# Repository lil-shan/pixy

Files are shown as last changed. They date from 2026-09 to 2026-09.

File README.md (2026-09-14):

# UNO Q LED Matrix

Driving a Waveshare 64×32 HUB75 RGB LED matrix from an Arduino UNO Q, with a
XIAO ESP32-S3 acting as the panel's display adapter.

All rendering — fonts, images, GIFs, scrolling, effects — runs in Python on the
UNO Q's Linux side. The ESP32 holds no application logic at all: it receives
finished RGB565 frames and copies them to the panel.

## Why there's a second microcontroller

A HUB75 panel has no framebuffer and no PWM of its own. Something must
continuously bit-bang thirteen signals at ~100+ full refreshes per second, with
binary code modulation layered on top for colour depth. That needs either DMA
hardware or a dedicated real-time core.

Neither half of the UNO Q can do it well. Linux userspace has no real-time
guarantee, so GPIO bit-banging flickers; and the standard Linux HUB75 library
(`rpi-rgb-led-matrix`) pokes BCM2835 registers directly and is Raspberry
Pi-specific. The STM32U585 is fast enough in principle, but Adafruit_Protomatter
has no U5 support — its STM32 backend is gated on `STM32F4_SERIES`.

So the pixel pump is offloaded to an ESP32-S3, which drives HUB75 over GDMA with
almost no CPU cost. It's the same reasoning you'd use to pick a dedicated
display driver IC. The interesting work stays on the UNO Q.

## Architecture

```
  ┌─────────────────────────┐         ┌──────────────────┐      ┌─────────┐
  │ UNO Q (Debian, Python)  │  WiFi   │ XIAO ESP32-S3    │HUB75 │ 64×32   │
  │ Pillow: text, images,   │────────►│ receives RGB565, │─────►│ panel   │
  │ GIFs, scrolling         │  TCP    │ blits via GDMA   │      │         │
  └─────────────────────────┘  :3333  └──────────────────┘      └─────────┘
                                                                     ▲
                                                     5V 2.5A supply ─┘
```

Measured throughput: **114 fps** over WiFi, **103 fps** over USB serial. A frame
is 4096 bytes (64×32 × RGB565), so the link was never the constraint.

## Hardware

| Part | Notes |
|---|---|
| Arduino UNO Q | Debian image `BUILD_ID=20251111-426` |
| Seeed XIAO ESP32-S3 | **External antenna required** — no PCB antenna |
| Waveshare RGB-Matrix-P3-64x32 | 1/16 scan, HUB75E connector |
| 5 V / 2.5 A supply | Panel only, via the VH4 socket |

## Wiring

HUB75 needs 13 signals. The XIAO exposes 11 edge GPIO plus four rear JTAG pads,
so two rear pads carry the two least timing-critical lines.

| HUB75 pin | Signal | XIAO | GPIO |
|---|---|---|---|
| 1 | R1 | D0 | 1 |
| 2 | G1 | D1 | 2 |
| 3 | B1 | D2 | 3 |
| 4 | GND | GND | — |
| 5 | R2 | D3 | 4 |
| 6 | G2 | D4 | 5 |
| 7 | B2 | D5 | 6 |
| 8 | E | *unconnected* | — |
| 9 | A | D6 | 43 |
| 10 | B | rear pad MTDI | 41 |
| 11 | C | rear pad MTDO | 40 |
| 12 | D | D7 | 44 |
| 13 | CLK | D8 | 7 |
| 14 | LAT | D9 | 8 |
| 15 | OE | D10 | 9 |
| 16 | GND | GND | — |

Pin 8 is the E address line, unused on a 1/16 scan panel. Power the panel from
its own 5 V supply — never from the XIAO's 5V pin — and keep grounds common.

## Control deck

| Control | Pin | Notes |
|---|---|---|
| Dial — CLK / DT / SW | D2 / D3 / D4 | HW-040 module |
| Up / Down / Left / Right | D8 / D9 / D10 / D11 | Big tactile, internal pull-ups |
| A / B | D12 / A1 | Small tactile |
| Buzzer | A0 | Passive piezo — an active one ignores the frequency |

One dial only. A second encoder was tried and abandoned; `enc(1)` is still
wired through and returns 0, so one can be added later without touching any
game.

## Controls

The grammar never varies, on any screen:

| Control | Always does |
|---|---|
| Dial | Move through choices, set a value |
| A | Confirm, act |
| B | Back, cancel |
| D-pad | Direction, inside games |

Every screen carries a hint bar saying what A and B do right now, every game
opens with a two-line help card, and a first-run tutorial makes you use each
control once before it lets you into the menus.

**Common rails.** All grounds are shorted together across the panel supply, the
XIAO, the UNO Q and every button return. Both HW-040 modules share one 3.3 V rail
from the UNO Q header.

**Feed the HW-040s from 3V3, not 5V.** They carry onboard pull-ups to VCC, so a
5 V supply puts 5 V onto the UNO Q's 3.3 V-logic inputs. Their onboard pull-ups
also mean you don't need external ones on CLK/DT.

**D13 is unusable as a button input.** It drives the onboard LED, whose series
resistor to ground divides against the ~40 kΩ internal pull-up and holds the pin
below threshold — a button there reads as permanently pressed. That's why B is
on A1.

See [BUILDLOG.md](BUILDLOG.md) for the full iteration history — every failure,
its cause and its fix.

## Enclosures

Two printed parts, each a tray plus a lid:

| File | Size | Holds |
|---|---|---|
| `case/enclosure/display_housing.stl` | 199 × 104 × 45 mm | panel, XIAO, power bank |
| `case/enclosure/handheld_controller.stl` | 128 × 88 × 35 mm | UNO Q, control deck, battery |

`case/pixy_case.scad` is an alternative single-piece desktop cabinet —
parametric, designed but not yet printed.

See [HACKSTER.md](HACKSTER.md) for the full build guide.

## Setup

**ESP32 side**

```bash
cp xiao_wifi/secrets.h.example xiao_wifi/secrets.h   # then fill in your SSID/password
arduino-cli compile --fqbn esp32:esp32:XIAO_ESP32S3 \
  --board-options USBMode=hwcdc -u -p /dev/ttyACM0 xiao_wifi
```

The panel displays its own IP address on boot, so no serial monitor is needed to
find it.

**UNO Q side**

```bash
sudo apt install -y python3-pil
python3 -c "
from panel import Panel
p = Panel(host='192.168.1.64')
p.text('HELLO')
"
```

## Learning games

Six, each with its own adaptive level:

| Game | Teaches |
|---|---|
| Gate Keeper | AND / OR / XOR / NAND / NOR |
| Bit Flip | binary place value |
| Pattern | arithmetic, geometric and Fibonacci sequences |
| Ohm's Way | V = I x R, and rearranging it |
| Gear Lab | ratios |
| Angle | degrees, with the dial as a protractor |

**They adapt independently, across eight levels.** Two first-try corrects in a
row moves that game up; two wrong answers moves it down. The bar to climb
rises with the level -- two in a row early, three from level 4, four from
level 6 -- so the top is earned rather than stumbled into. Roughly twenty
clean answers to reach level 8.

What changes as you climb:

| Game | At the top |
|---|---|
| Gates | the gate stops telling you what it is; deduce it by experiment |
| Bit Flip | 8 bits, and the running total is hidden -- sum it yourself |
| Pattern | squares and growing-gap sequences, not just constant steps |
| Ohm's Way | awkward numbers, any of the three unknown |
| Gear Lab | real ratios like 5:3, not whole multiples |
| Angle | any angle, no readout, within 3 degrees by eye |

Two first-try corrects in a row moves that game up a level; two wrong moves it
down. A kid who has binary cold but
finds ratios hard gets hard binary and gentle ratios at the same time, which a
single global difficulty could never do. Charge paid scales with level, so
pushing yourself beats farming easy rounds.

**They explain.** A wrong answer opens a one-line card saying *why* -- "V = I
X R / 3 X 3 = 9", "5 IS / 4+1", "ADD 4 EACH / SO 19" -- then puts you back on
the same problem. Being told you are wrong teaches nothing on its own.

## API

```python
from panel import Panel

p = Panel(host='192.168.1.64')   # WiFi
p = Panel()                      # or USB serial, autodetected

p.text('HELLO')                            # centred, auto-shrinks to fit
p.scroll('longer message', speed=0.02)     # any length, any font
p.image('logo.png')                        # scaled, aspect preserved
p.gif('animation.gif')                     # honours per-frame timing
p.brightness(60)
p.clear()
p.ping()                                   # round-trip check
```

## Protocol

```
0xA5 0x5A <cmd> <len:uint16 LE> <payload...>
  0x01  frame       4096 bytes RGB565, big endian per pixel
  0x02  brightness  1 byte
  0x03  clear       no payload
  0x04  ping        no payload
```

Each handled command is acknowledged with a single `0x06` byte, so the host can
verify delivery rather than relying on someone watching the panel.

## Sketches

| Sketch | Purpose |
|---|---|
| `xiao_wifi` | **Main.** WiFi receiver, TCP server on :3333 |
| `xiao_receiver` | Same receiver over USB serial |
| `xiao_panel` | Standalone demo — colour bars, scrolling text, bitmap |
| `xiao_diag` | Slow static diagnostic: flat fills, half-split, row sweep |
| `xiao_addr` | Identifies which address line is wired where |

## Things that bit us

Kept because every one cost real debugging time.

- **The XIAO ESP32-S3 has no PCB antenna.** Without the u.FL antenna attached it
  saw 4 networks at −85 dBm and could not associate. With it: 16 networks,
  −39 dBm. A 45 dB difference that presents as "wrong WiFi password".
- **`Tinker Space` was 5 GHz only.** The ESP32-S3 is 2.4 GHz only, so it could
  never have joined regardless of credentials.
- **Address lines B and D were crossed.** Every row lit, but in scrambled order —
  a pure permutation. Fixed in software by swapping the pin defines; `xiao_addr`
  identifies the mapping in one static image.
- **USB CDC RX buffer defaults to 256 bytes.** Against a 4096-byte frame, every
  full frame arrived truncated while ping and brightness worked perfectly.
  `Serial.setRxBufferSize(8192)` before `begin()`.
- **Reading the two magic bytes in one pass desynchronises the stream** whenever
  `0xA5` lands at the end of a USB packet. Track the previous byte across loop
  iterations instead.
- **pyserial asserts DTR and RTS on open**, which on the S3's USB Serial/JTAG
  peripheral drives reset and boot-mode selection. Clear both *before* opening.
- **Driving an unpowered panel back-feeds it** through the input ESD clamp
  diodes, lighting it dimly with garbage and browning out the XIAO. Power the
  panel first, then the XIAO.

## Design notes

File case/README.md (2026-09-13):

# Pixy enclosure

A wedge cabinet. The LED panel leans back ~10°, the control deck slopes ~18°
toward the player. Three printed parts, none needing supports.

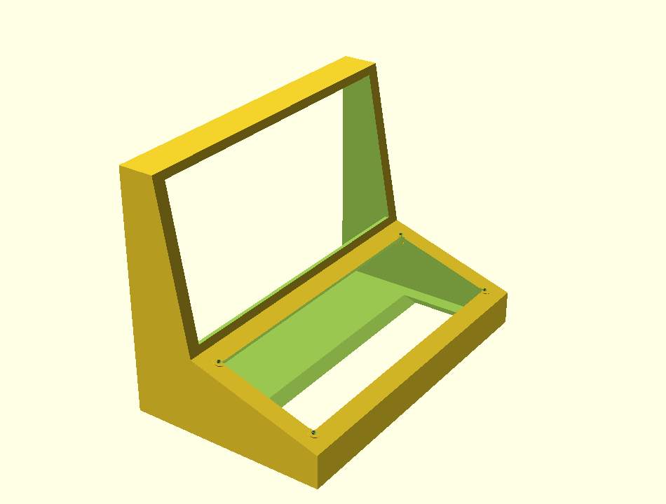
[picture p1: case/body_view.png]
body


## Parts

| Part | Size (mm) | Material | Orientation |
|---|---|---|---|
| `body` | 127 × 210 × 156 | ~194 g | On its **back face**, flat on the bed |
| `deck` | 83 × 203 × 3 | ~60 g | Flat |
| `back` | 203 × 153 × 3 | ~99 g | Flat |

Figures are 100% infill. At 20% with 3 perimeters expect roughly 40–50% of
that, so around **150 g** for the set.

**You need a 220 × 220 bed.** The widest part is 210 mm. Tell me if yours is
smaller and I'll add a split with alignment pins — `W` is parametric, but the
panel is 192 mm wide so the cabinet cannot shrink below about 206 mm.

## Print settings

- 0.2 mm layers, 3 perimeters, 20% infill
- No supports. Every overhang is either a wall or the ~18° deck, both fine
- Brim on `body` — it is tall with a modest footprint

## Assembly

1. **Panel** drops into the recess behind the screen aperture, from inside.
   The aperture is 4 mm smaller than the panel all round, so it seats against
   that lip and can't fall forward. Retain it with a dab of hot glue at each
   corner, or four small printed clips.
2. **Controls** push into the `deck` plate from behind: encoders through the
   7.6 mm holes with their own nuts, 12 mm tactiles into the big holes, 6 mm
   into the small pair, piezo behind the grille.
3. **Deck** sits on the ledge and screws down into the four bosses with M3 ×
   10. The plate sits proud by 3 mm — deliberate, so the ledge takes the load
   rather than the panel face.
4. **UNO Q and XIAO** mount inside on the base. There's room behind the deck.
5. **Back cover** screws on last. The vent slots sit over the UNO Q, and the
   cable exit at the bottom takes the panel's 5 V feed.

## Before you print

Three dimensions in the `.scad` are estimates I could not verify. Measure
yours and edit the top of the file — everything else derives from them.

```
panel_w = 192;   // confirmed from Waveshare's spec
panel_h = 96;    // confirmed
pcb_t   = 8;     // ESTIMATE  bare PCB depth
back_t  = 14;    // ESTIMATE  total depth including IDC connectors
```

`pcb_t` is the one that matters. Too small and the panel won't seat; too large
and it rattles. Measure the PCB alone, not including the connectors.

Also check `clear = 0.4`. That is the slip fit between printed parts — raise
it if your printer runs tight.

## Rendering

```bash
openscad -D 'part="body"' -o body.stl pixy_case.scad
openscad -D 'part="deck"' -o deck.stl pixy_case.scad
openscad -D 'part="back"' -o back.stl pixy_case.scad
```

Leave `part` unset to see all three laid out together.

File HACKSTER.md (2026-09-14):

# Pixy — a handheld STEM console that runs on what you learn

**Solve engineering puzzles on a 64×32 LED matrix, bank the Charge you earn,
and spend it in the arcade. Two wireless units, built on the Arduino UNO Q —
and it uses both of its brains.**

> 📷 `docs/img/screens/console-home.jpeg` — the console, powered up
> 🎬 **VIDEO — upload `pixyvideo5.mp4` to YouTube and embed here.** Pattern
> solved, then a **LEVEL 2** promotion banner. It shows the adaptive system
> working in five seconds, better than any paragraph.

---

## Why I built this

Most STEM toys pick a side. Either they teach, and feel like homework with
LEDs on it — or they entertain, and the learning is a thin coat of paint over
a game the kid would rather just play.

Pixy makes the learning **the power source**. Every puzzle you solve pays
*Charge*. Charge is what unlocks the arcade — Breakout, Pong, Snake, Simon. A
kid who wants to play Pong gets there by working out gear ratios. That is the
entire design, and everything else follows from it.

Two decisions came out of that, and both went against my first instinct:

**Arcade unlocks are permanent, not pay-per-play.** Charging per play turns
learning into a toll booth, and a kid who runs short simply stops. A one-time
unlock gives you something to work toward that then keeps giving.

**Difficulty adapts per game, not globally.** A kid who has binary cold but
finds ratios hard should get hard binary and gentle ratios *at the same time*.
One global difficulty slider can only ever hold one back while overwhelming
the other.

---

## What it is

Two units that talk over WiFi, each with its own power.

| | |
|---|---|
| **Handheld** | Arduino UNO Q, the control deck, a battery. Runs every game. |
| **Display** | 64×32 LED matrix, XIAO ESP32-S3, a power bank. Draws what it is told. |

> 📷 `docs/img/screens/gates.jpeg` — Gate Keeper
> 📷 `docs/img/screens/gearlab-close.jpeg` — Gear Lab, both wheels turning
> 📷 `docs/img/screens/ohms-way.jpeg` — Ohm's Way

**Six learning games:** Gates (boolean logic), Bit Flip (binary), Pattern
(sequences), Ohm's Way (V = I × R), Gear Lab (ratios), Angle (degrees).

**Four arcade games:** Breakout (free), Simon (40 Charge), Snake (60),
Pong (80).

---

## How it works

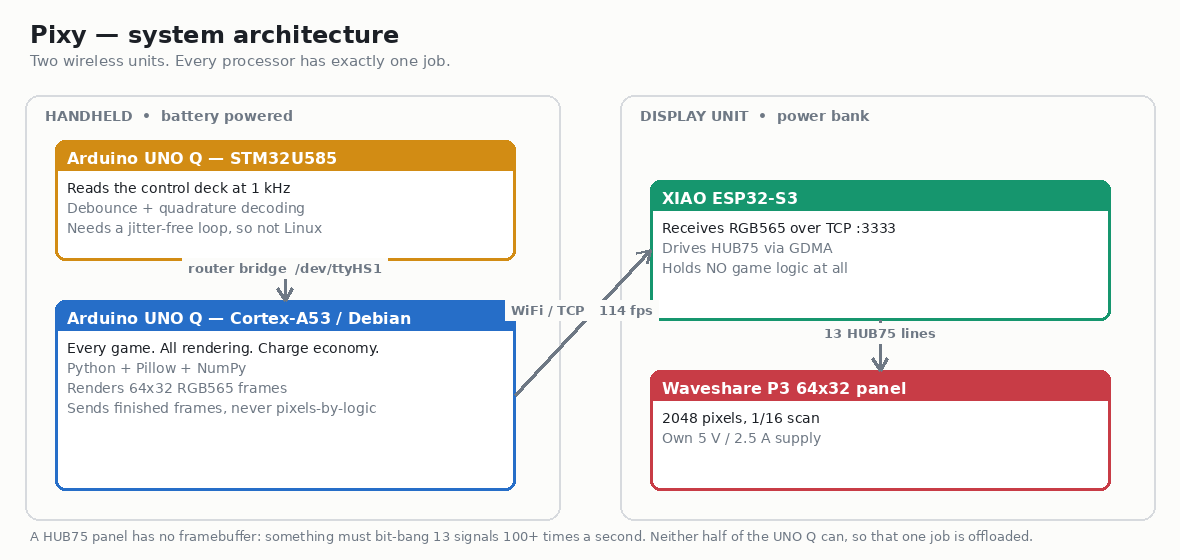
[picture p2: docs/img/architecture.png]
architecture


Three processors, one job each.

| Processor | Job | Why this one |
|---|---|---|
| **STM32U585** (on the UNO Q) | Reads the control deck at 1 kHz | Quadrature decoding and debounce need a jitter-free loop. Linux userspace has no real-time guarantee. |
| **Cortex-A53 / Debian** (on the UNO Q) | Every game, all rendering, the Charge economy | Python, Pillow, real fonts, a real filesystem for save state. |
| **XIAO ESP32-S3** | Pixel pump for the panel | See below. |

### Why there is a third microcontroller

A HUB75 LED panel has **no framebuffer and no PWM**. Something must bit-bang
thirteen signals at 100+ full refreshes a second, with binary code modulation
layered on for colour depth. That needs DMA hardware or a dedicated real-time
core.

Neither half of the UNO Q has it. Linux userspace flickers, and the standard
Linux HUB75 library (`rpi-rgb-led-matrix`) pokes BCM2835 registers directly —
it is Raspberry Pi-specific. On the MCU side, Adafruit's Protomatter has no
STM32U5 backend; its STM32 support is gated on `#if defined(STM32F4_SERIES)`.

So that one job is offloaded to a XIAO ESP32-S3, which drives HUB75 over GDMA
at almost no CPU cost. **It holds no game logic whatsoever** — it receives
finished RGB565 frames and copies them to the panel. A display adapter,
exactly as you would use a dedicated driver IC.

Measured: **114 fps over WiFi**. A frame is 4096 bytes, so the link was never
the constraint.

---

## Parts

| Part | Qty | Notes |
|---|---|---|
| Arduino UNO Q | 1 | Debian image `20251111-426` or newer |
| Seeed XIAO ESP32-S3 | 1 | **the u.FL antenna is not optional** |
| Waveshare RGB-Matrix-P3-64×32 | 1 | 192 × 96 mm, 1/16 scan |
| EC11 / HW-040 rotary encoder | 1 | with push switch |
| 12 mm tactile switch | 4 | direction cluster |
| 6 mm tactile switch | 2 | A and B |
| Passive piezo buzzer | 1 | **passive** — an active one ignores the frequency |
| 5 V power bank, 2.5 A+ | 1 | display unit |
| Battery pack | 1 | handheld |
| Perfboard, jumper wire, M3 screws | — | |

**Tools:** soldering iron, multimeter, 3D printer (220 × 220 bed).

---

## Quick start

If you are comfortable with Arduino, this is the whole thing:

```bash
git clone https://github.com/lil-shan/pixy && cd pixy

# 1. Display unit — flash the XIAO
cp xiao_wifi/secrets.h.example xiao_wifi/secrets.h   # your 2.4 GHz SSID
arduino-cli compile --fqbn esp32:esp32:XIAO_ESP32S3 \
  --board-options USBMode=hwcdc -u -p /dev/ttyACM0 xiao_wifi

# 2. Handheld — flash the UNO Q's MCU
arduino-cli compile --fqbn arduino:zephyr:unoq -u -p /dev/ttyACM1 mcu/pixy_input

# 3. Copy the Python side to the UNO Q, then run it
scp -r host/* arduino@<uno-q-ip>:~/ledmatrix/
ssh arduino@<uno-q-ip> 'cd ledmatrix && ./pixy.sh start <xiao-ip>'
```

The panel shows its own IP on boot, so you never need a serial monitor to find
it. **The ESP32-S3 is 2.4 GHz only** — a 5 GHz SSID will never work, however
right the password is.

The detailed version follows.

---

## Build it, step by step

### Step 1 — Display unit: panel and XIAO

> 📷 `docs/img/build/02-xiao-antenna.jpeg` — XIAO with its antenna fitted

**Fit the antenna first.** The XIAO ESP32-S3 has no PCB antenna. There is a
small u.FL socket; the flexible antenna in the box clips onto it, pressed
straight down until it clicks. Without it the radio is deaf — see the bugs
section, because this cost me an evening.

HUB75 needs 13 signals. The XIAO has 11 edge GPIO plus four rear JTAG pads, so
the two least timing-critical lines go on the rear pads.

| HUB75 | XIAO | | HUB75 | XIAO |
|---|---|---|---|---|
| R1 | D0 · GPIO1 | | A | D6 · GPIO43 |
| G1 | D1 · GPIO2 | | B | rear `MTDI` · GPIO41 |
| B1 | D2 · GPIO3 | | C | rear `MTDO` · GPIO40 |
| R2 | D3 · GPIO4 | | D | D7 · GPIO44 |
| G2 | D4 · GPIO5 | | CLK | D8 · GPIO7 |
| B2 | D5 · GPIO6 | | LAT | D9 · GPIO8 |
| GND | GND | | OE | D10 · GPIO9 |

Pin 8 (E) is unused on a 1/16 scan panel — leave it disconnected.

**Finding pin 1 without labels:** HUB75 connectors rarely print signal names.
Set a multimeter to continuity, put one probe on the panel's ground terminal
and walk the other across all 16 pins. One column has **no** grounds — that is
the odd column, and pin 1 is at the end where the even column's ground is its
*second* pin.

**Power the panel from its own 5 V supply**, never from the XIAO's 5V pin, and
keep grounds common between the supply, the panel and the XIAO.

⚠️ **Power the panel first, then the XIAO.** Driving an unpowered panel
back-feeds it through the input ESD clamp diodes, lighting it dimly with
garbage and browning out the XIAO.

Flash `xiao_wifi`, and the panel will show `WIFI …` then its own IP address.

> 📷 `docs/img/build/05-wifi-connecting.jpeg` — the panel connecting

### Step 2 — Handheld: the control deck

> 📷 `docs/img/build/03-deck-perfboard.jpeg` — the deck on perfboard
> 📷 `docs/img/build/01-unoq-deck-wiring.jpeg` — wiring it to the UNO Q

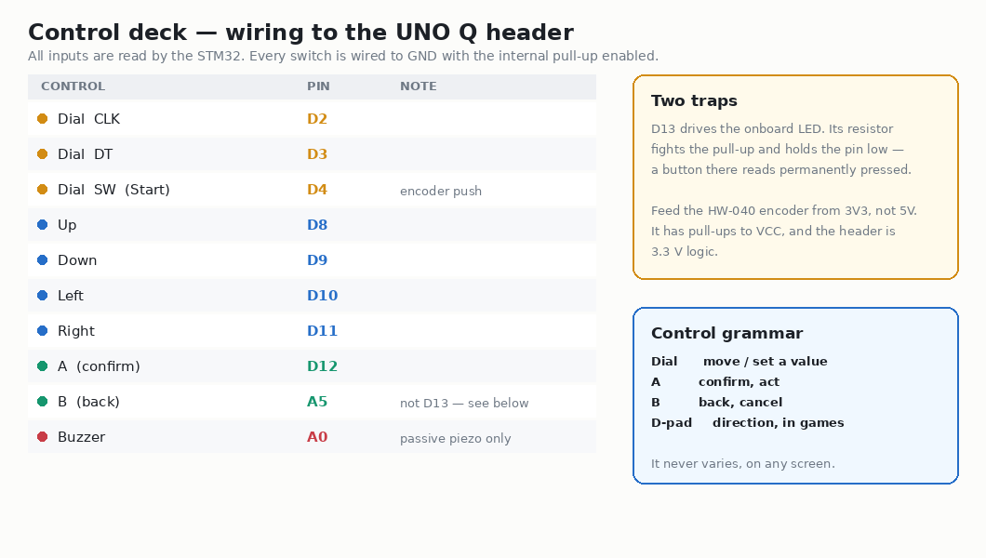
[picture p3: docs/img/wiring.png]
wiring


Everything mounts on a piece of perfboard: four 12 mm tactile switches in a
diamond for direction, two 6 mm for A and B, and the rotary encoder. Each
switch has one leg to its pin and the other to ground — the internal pull-ups
do the rest, so no resistors are needed.

| Control | Pin |
|---|---|
| Dial — CLK / DT / SW | D2 / D3 / D4 |
| Up / Down / Left / Right | D8 / D9 / D10 / D11 |
| A | D12 |
| B | A5 |
| Buzzer | A0 |

⚠️ **Feed the HW-040 encoder module from 3V3, not 5V.** It carries onboard
pull-ups to VCC, so a 5 V supply puts 5 V onto the UNO Q's 3.3 V-logic inputs.

⚠️ **Do not put a button on D13.** It drives the onboard LED, whose series
resistor to ground fights the internal pull-up and holds the pin below
threshold. A button there reads as *permanently pressed*.

Flash the MCU sketch:

```bash
arduino-cli compile --fqbn arduino:zephyr:unoq -u -p /dev/ttyACM1 mcu/pixy_input
```

It scans all inputs at 1 kHz, debounces them, decodes the encoder with a
16-entry quadrature table, and packs the lot into a single 32-bit word that
Python reads once per frame:

```
bits  0-7   buttons held now
bits  8-15  buttons pressed since last poll  (latched, cleared on read)
bits 16-23  encoder delta, signed
bits 24-31  reserved for a second encoder
```

Latching presses on the MCU means a tap between two 30 fps polls is never
lost.

### Step 3 — The software side

The Python bridge API and Pillow live **inside the App Lab brick container**,
not on the host, so `import arduino` fails over SSH. Rather than fight that,
Pixy runs inside that container with the router socket mounted — which means
**no `sudo apt install` is needed at all**:

```bash
docker run -d --name pixy --restart unless-stopped --network host \
  -v /var/run/arduino-router.sock:/var/run/arduino-router.sock \
  -v /home/arduino/ledmatrix:/app -w /app \
  --entrypoint python3 ghcr.io/arduino/app-bricks/python-apps-base:0.12.0 \
  -m pixy.app <xiao-ip>
```

`board/pixy.sh` wraps that up:

```bash
./pixy.sh start <xiao-ip>   # detached, survives logout and reboot
./pixy.sh deck              # input tester instead
./pixy.sh status            # what is running, is the panel connected
./pixy.sh logs
./pixy.sh stop
```

**Check the deck before anything else.** `./pixy.sh deck` lights a dot per
button and moves a bar for the dial. Every control should respond. If a button
reads as permanently held, it is almost always a 4-pin tactile switch wired
across an internally-connected pair — rotate one leg 90°.

### Step 4 — Print the enclosures

Two printed parts, each a tray and a lid.

| File | Size | Holds |
|---|---|---|
| `case/enclosure/display_housing.stl` | 199 × 104 × 45 mm | panel, XIAO, power bank |
| `case/enclosure/handheld_controller.stl` | 128 × 88 × 35 mm | UNO Q, control deck, battery |

> 📷 `docs/img/build/04-deck-in-shell.jpeg` — the deck in its printed shell

Both print flat with no supports. The handheld's tray has an internal ledge
for the perfboard to sit on.

*(An alternative single-piece desktop cabinet is also in `case/` as parametric
OpenSCAD — designed but not yet printed.)*

### Step 5 — First run

Power the display unit, then the handheld. On first boot Pixy runs a short
**tutorial** that makes you turn the dial, press A and press B before it lets
you into the menus — three steps, one dot each.

> 📷 `docs/img/screens/home.jpeg` — the Home menu

---

## The part I am proudest of

### It explains when you get it wrong

Being told you are wrong teaches nothing. A wrong answer opens a one-line card
saying **why**, then puts you back on the same problem.

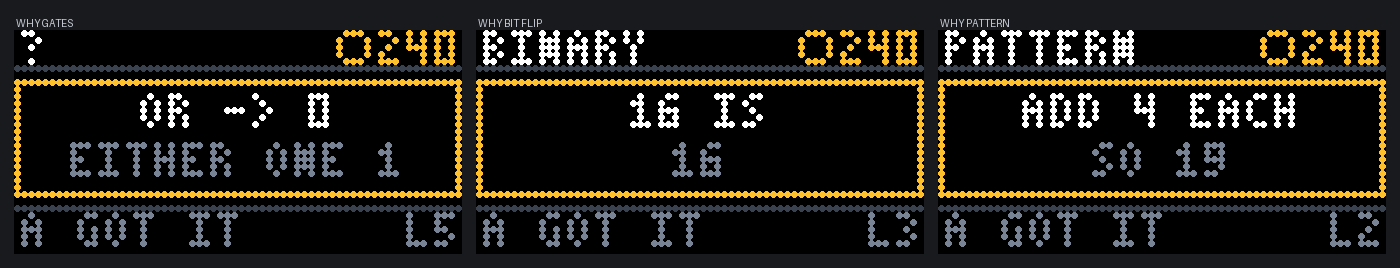
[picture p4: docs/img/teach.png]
teach


- `V = I X R` / `3 X 3 = 9`
- `5 IS` / `4+1`
- `ADD 4 EACH` / `SO 19`

### Difficulty follows you — per game

Every game carries **its own level, 1 to 8**. Two first-try corrects in a row
promotes; two wrong answers demotes.

Only a **first-try** answer counts toward promotion — arriving after three
guesses is not the same as knowing it. The bar also rises as you climb: two in
a row early, three from level 4, four from level 6. Roughly twenty clean
answers to reach the top.

And the games change *character* near the top, not just their numbers:

| Game | At level 8 |
|---|---|
| Gates | **the gate stops telling you what it is** — flip inputs, watch the output, deduce it |
| Bit Flip | 8 bits, running total **hidden**, sum it yourself |
| Pattern | squares and growing-gap sequences |
| Ohm's Way | awkward numbers, any of the three unknown |
| Gear Lab | real ratios like 5:3, not whole multiples |
| Angle | any angle, **no readout**, within 3° by eye |

Charge scales with level, and a speed bonus pays more for a quick first-try
answer — so pushing your level beats farming easy rounds.

---

## Five bugs worth writing down

Every one of these presented as something else entirely.

**1. The XIAO ESP32-S3 has no PCB antenna.** Without the u.FL antenna clipped
on it saw 4 networks at −85 dBm and could not associate. With it: 16 networks
at −39 dBm. **A 45 dB difference that presents as "wrong WiFi password."**

**2. USB CDC's receive buffer defaults to 256 bytes.** Against a 4096-byte
frame every full frame arrived truncated — while ping and brightness commands
worked perfectly, because they were small. `Serial.setRxBufferSize(8192)`
before `begin()`.

**3. The MCU registered its RPCs once, in `setup()`.** The MCU boots in
milliseconds; Linux takes ~40 s to start `arduino-router`. So on any cold boot
the registration silently failed and the controls were dead until someone
reflashed — which would have happened on stage. It now retries from `loop()`
until the router answers.

**4. A swapped CLK and SW is invisible from software.** The decoder reads a
static pin as CLK against a live DT, producing an endless +1/−1 that never
reaches a whole detent. The encoder reads exactly zero — *identical to a
disconnected encoder*. Every test said "no signal" while the signal was there
on the wrong pin.

**5. A dark fill behind selected text made it harder to read, not easier.** On
an LED panel there is no backlight: every pixel you light in the background
costs contrast against the glyphs. Selection is now pure brightness — white
row, coloured caret, dimmed neighbours, no fill.

---

## What's next

- **Level packs as JSON.** The engines exist; content should be data, so a
  teacher — or a kid — can author levels without touching Python.
- **Camera games** using App Lab's AI bricks.
- **Two-player Pong** with a second dial.
- **Sound.** `beep()` is wired throughout and needs only a piezo on A0. Sound
  is most of what separates a hardware toy from a prototype.

---

## Files

Everything is at **github.com/lil-shan/pixy** — MIT licensed.

| | |
|---|---|
| `host/pixy/` | the console: games, shell, adaptive difficulty |
| `mcu/pixy_input/` | STM32 control deck scanner |
| `xiao_wifi/` | panel driver |
| `case/enclosure/` | printed enclosures (STL) |
| `board/pixy.sh` | launcher |
| `BUILDLOG.md` | every failure and its cause, in order |

*About 2,500 lines of Python, 440 of Arduino, and a 3×5 pixel font drawn by
hand because PIL's smallest is three times too tall for a 32-row screen.*

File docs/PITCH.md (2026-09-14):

# Pixy — pitches

## One line (Hackster summary field, bios, tweets)

A handheld STEM console where you have to earn the arcade: solve engineering
puzzles on a 64×32 LED matrix to bank Charge, then spend it on Breakout, Pong
and Snake.

## Ten seconds (someone walks up to the table)

> It's a games console for kids where the games are locked. You unlock them by
> solving engineering puzzles — logic gates, gear ratios, Ohm's law. Solve one,
> earn Charge. Charge buys Pong.

Then hand it to them. The object sells itself faster than any sentence.

## Thirty seconds (a judge, a teacher, a parent)

> Most STEM toys pick a side. Either they teach and feel like homework, or they
> entertain and the learning is a thin coat of paint.
>
> Pixy makes the learning the power source. Every puzzle you solve pays Charge,
> and Charge is the only way into the arcade. A kid who wants to play Pong gets
> there by working out gear ratios.
>
> Two things make it actually work. It **explains when you're wrong** — a wrong
> answer tells you *why* in one line, then puts you back on the same problem.
> And difficulty **adapts per subject, not globally** — so a kid who has binary
> cold but finds ratios hard gets hard binary and gentle ratios at the same
> time. One slider could never do that.
>
> It's two wireless units on an Arduino UNO Q: the handheld runs every game in
> Python on the Linux side, while the STM32 reads the controls at 1 kHz.

## For an Arduino UNO Q audience (why this board)

> Pixy uses both of the UNO Q's brains on the critical path, which is the whole
> argument for the board. The STM32 scans the control deck at 1 kHz — quadrature
> decoding and debounce need a jitter-free loop, and Linux userspace has no
> real-time guarantee. The Linux side runs every game in Python with Pillow,
> which is what makes six learning games and an adaptive difficulty engine a
> weekend of work instead of a month.
>
> The one thing neither half can do is drive a HUB75 panel — that needs DMA or a
> dedicated real-time core, and Protomatter has no STM32U5 backend. So that one
> job is offloaded to a XIAO over WiFi, at 114 fps. The ESP32 holds no game
> logic at all; it's a display adapter.

## The line to end on

> The arcade is the reward, but the point is that a kid works out a gear ratio
> to get there — and if they get it wrong, the console tells them why.

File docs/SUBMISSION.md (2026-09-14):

# Hackster.io submission checklist

Paste `HACKSTER.md` into the Story editor. Everything else below fills in the
sidebar fields.

## Things used in this project

**Hardware components**
- Arduino UNO Q — ×1
- Seeed Studio XIAO ESP32-S3 — ×1
- Waveshare RGB full-colour LED matrix panel, P3, 64×32 — ×1
- Rotary encoder with push button (EC11 / HW-040) — ×1
- Tactile switch, 12 mm — ×4
- Tactile switch, 6 mm — ×2
- Passive piezo buzzer — ×1
- 5 V 2.5 A power supply — ×1
- Jumper wires, perfboard, M3 screws

**Software apps and online services**
- Arduino App Lab
- Arduino IDE / arduino-cli
- Python 3 with Pillow and NumPy
- OpenSCAD

**Hand tools and fabrication machines**
- Soldering iron
- Multimeter
- 3D printer (220 × 220 bed minimum)

## Code
Link the repo: `https://github.com/lil-shan/pixy`
Hackster can import it directly — use "Add code" → GitHub.

## Custom parts and enclosures
Upload from `case/enclosure/`:
- `display_housing.stl` — 199 × 104 × 45 mm, holds panel + XIAO + power bank
- `handheld_controller.stl` — 128 × 88 × 35 mm, holds UNO Q + deck + battery

Optional, from `case/` — an alternative desktop cabinet, designed but not
printed. Only include it if you want to show the direction, and label it as
unbuilt:
- `pixy_case.scad`, `body.stl`, `deck.stl`, `back.stl`

## Images to upload

Real photographs first — they carry the project far better than renders.

| File | Use as |
|---|---|
| `docs/img/screens/console-home.jpeg` | **cover image** |
| `docs/img/architecture.png` | how it works |
| `docs/img/wiring.png` | control deck wiring |
| `docs/img/build/02-xiao-antenna.jpeg` | step 1 |
| `docs/img/build/05-wifi-connecting.jpeg` | step 1 |
| `docs/img/build/03-deck-perfboard.jpeg` | step 2 |
| `docs/img/build/01-unoq-deck-wiring.jpeg` | step 2 |
| `docs/img/build/04-deck-in-shell.jpeg` | step 4 |
| `docs/img/screens/home.jpeg` | step 5 |
| `docs/img/screens/gates.jpeg` | what it is |
| `docs/img/screens/gearlab-close.jpeg` | what it is |
| `docs/img/screens/ohms-way.jpeg` | what it is |
| `docs/img/teach.png` | teach-on-error |

## Videos — upload to YouTube, then embed

| Source file | Where it goes | Why |
|---|---|---|
| `pixyvideo5.mp4` | **top of the story** | Pattern solved, then a LEVEL 2 promotion banner. Shows adaptive difficulty working in 5 seconds |
| `pixyvideo6.mp4` | arcade section | Breakout played on the dial |
| `pixyvideo2.mp4` or `pixyvideo3.mp4` | what it is | someone holding and playing it |

The promotion-banner clip is the single most valuable asset you have. Lead
with it.

## Suggested tags
`arduino-uno-q` `led-matrix` `hub75` `esp32` `education` `stem` `retro-gaming`
`python` `3d-printing`

## One-line summary (Hackster's summary field)
A handheld STEM console where you have to earn the arcade: solve engineering
puzzles on a 64×32 LED matrix to bank Charge, then spend it on Breakout, Pong
and Snake.

Longer pitches for demos and judging are in [PITCH.md](PITCH.md).

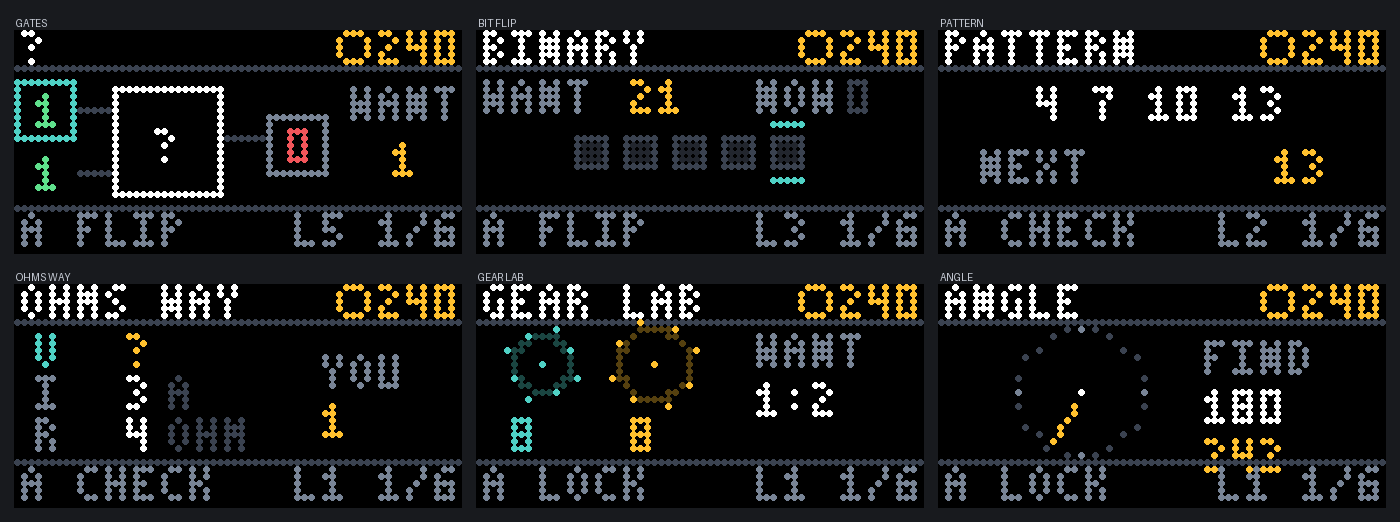
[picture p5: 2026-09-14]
docs/img/learn.png

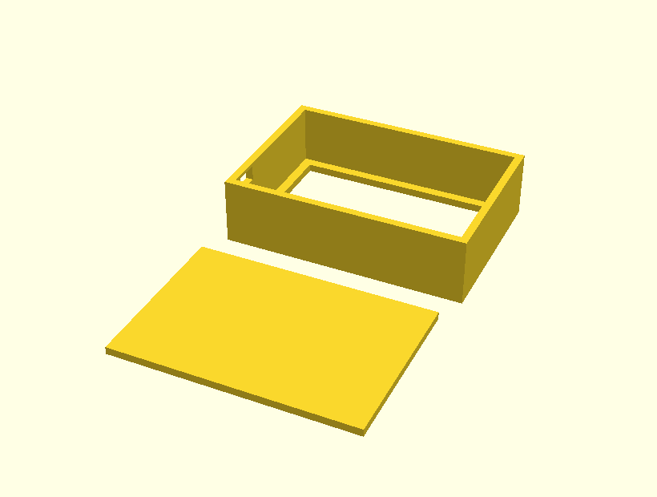
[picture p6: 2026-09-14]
docs/img/handheld_controller.png

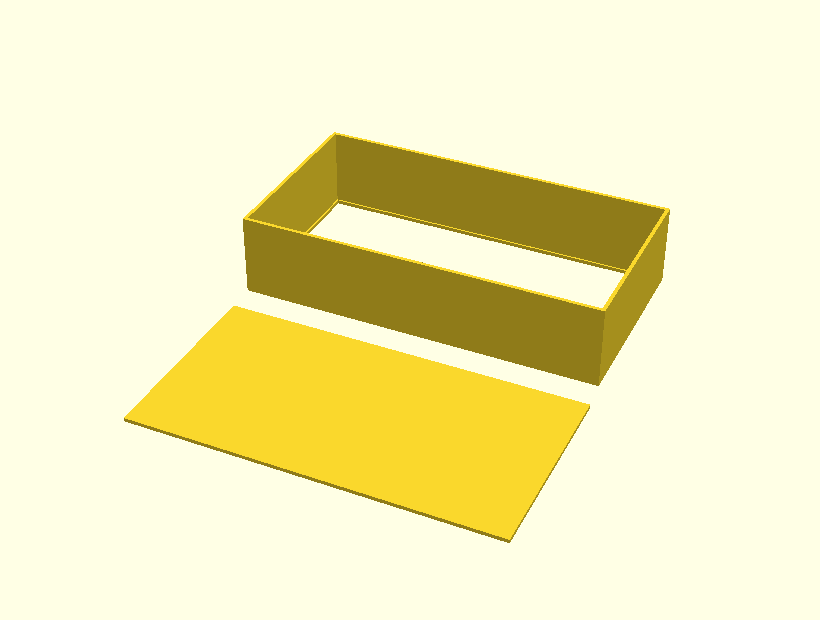
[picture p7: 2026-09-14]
docs/img/display_housing.png

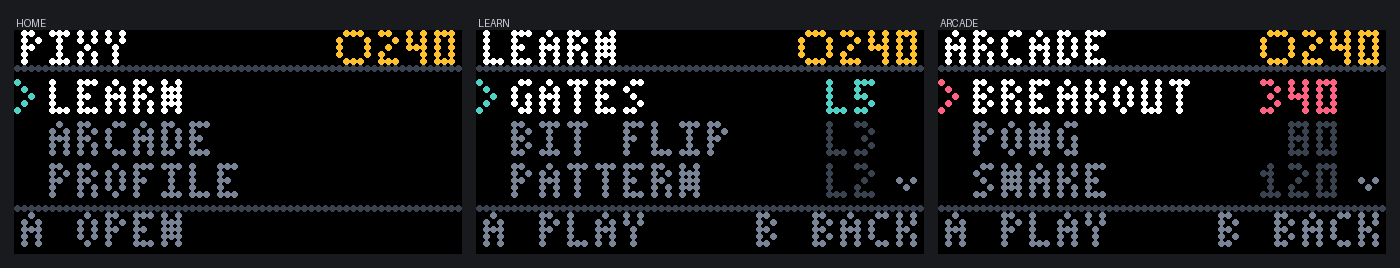
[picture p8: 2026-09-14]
docs/img/shell.png

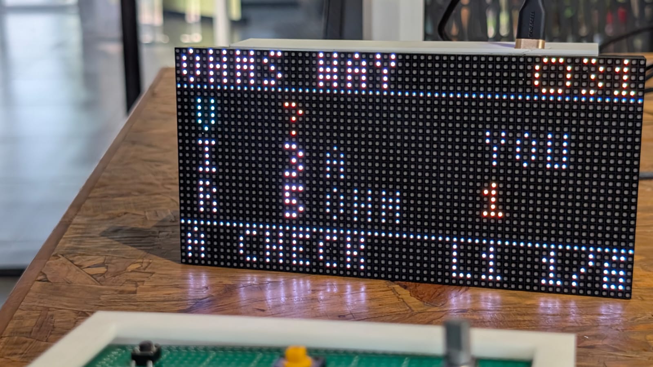
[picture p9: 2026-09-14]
docs/img/screens/ohms-way.jpeg

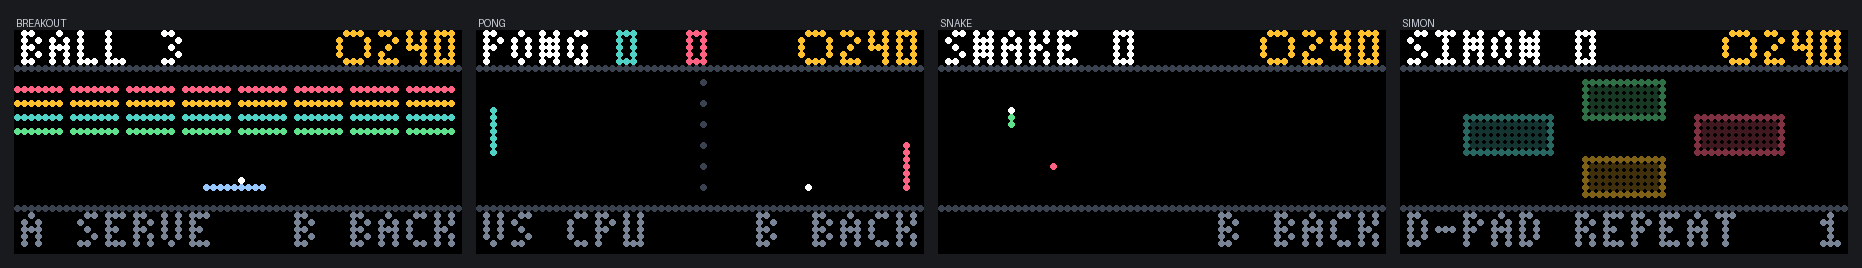
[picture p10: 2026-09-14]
docs/img/arcade.png

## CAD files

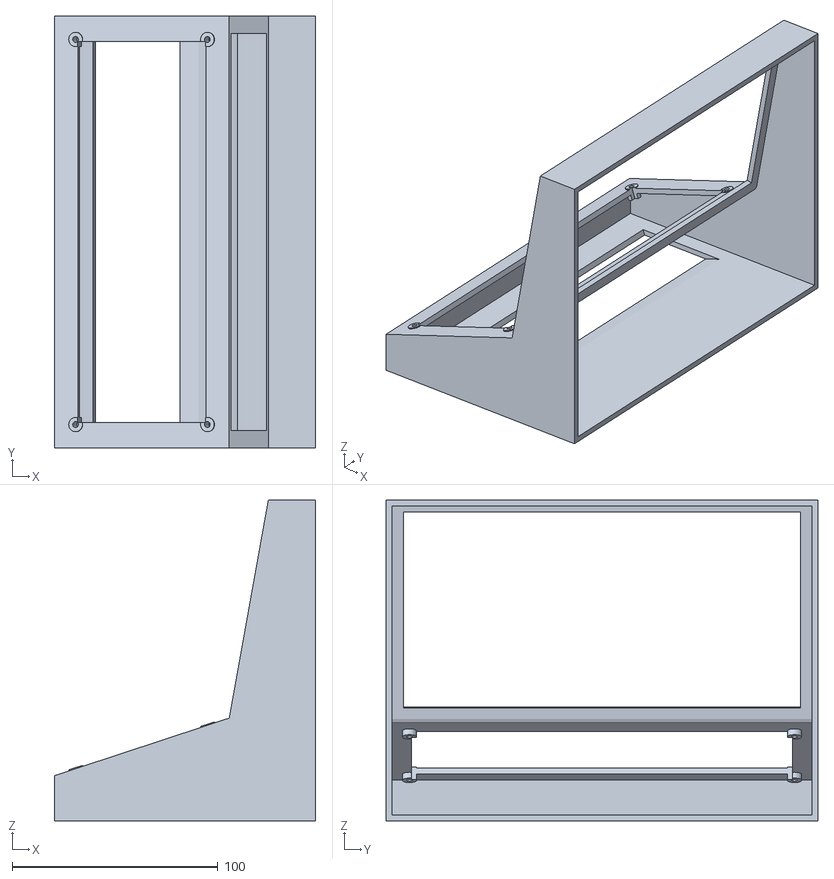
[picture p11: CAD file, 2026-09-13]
case/body.stl
127.0 x 210.0 x 156.0

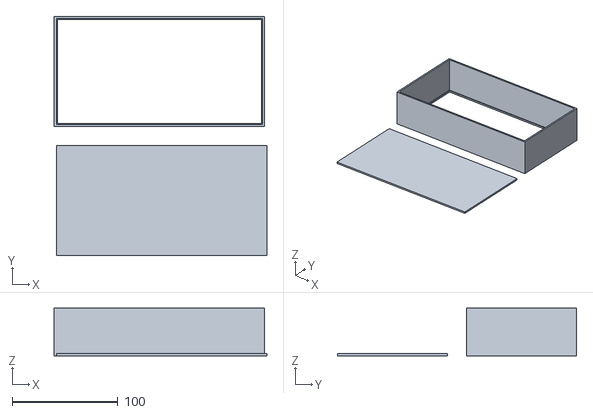
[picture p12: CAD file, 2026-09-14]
case/enclosure/display_housing.stl
201.0 x 226.0 x 45.0

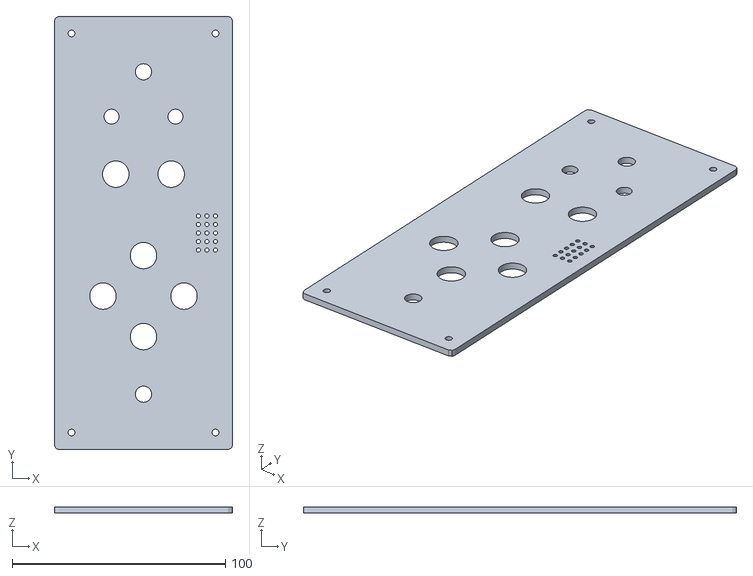
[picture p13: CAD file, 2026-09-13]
case/deck.stl
83.5 x 203.2 x 3.00

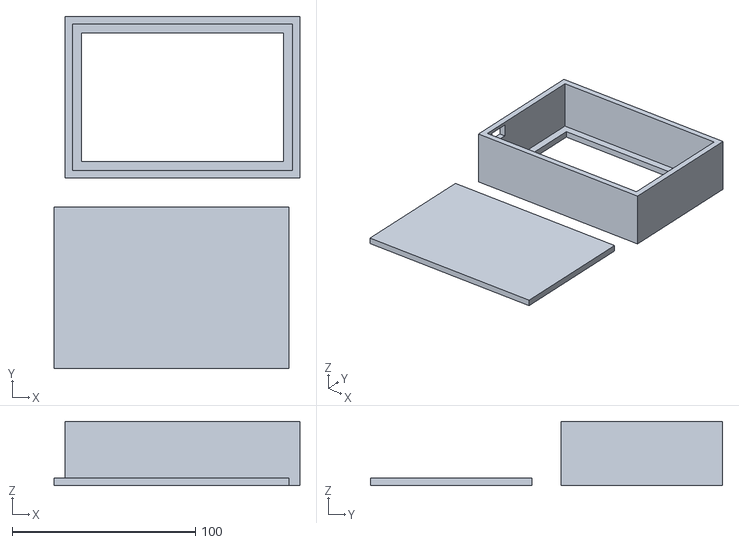
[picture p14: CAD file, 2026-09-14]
case/enclosure/handheld_controller.stl
134.0 x 192.0 x 35.0

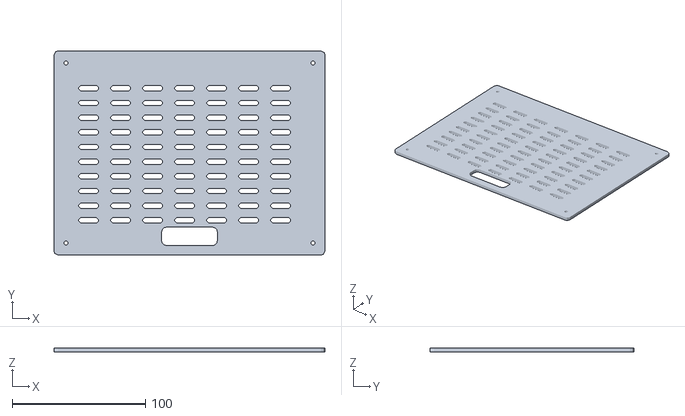
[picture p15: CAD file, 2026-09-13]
case/back.stl
203.2 x 153.0 x 3.00

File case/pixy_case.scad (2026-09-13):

// Pixy — desktop console enclosure
//
// A wedge cabinet: the LED panel leans back ~10 deg, the control deck slopes
// ~18 deg toward the player. Three printed parts, no supports needed.
//
//   body   the wedge shell. Screen aperture with a lip the panel rests on
//          from behind, deck opening with bosses, open rear.
//   deck   flat control plate. Sits on top of the deck opening and screws
//          down, so the panel face carries no load.
//   back   rear cover, vented, with a cable exit.
//
//   openscad -D 'part="deck"' -o deck.stl pixy_case.scad
//
// MEASURE THESE before printing -- everything else is derived.
panel_w = 192;   // Waveshare P3 64x32 active area (confirmed)
panel_h = 96;
pcb_t   = 8;     // ESTIMATE: bare PCB depth, no connectors
back_t  = 14;    // ESTIMATE: total depth including the IDC connectors

wall      = 3;
bezel_lip = 4;     // overlap holding the panel in from the front
clear     = 0.4;   // slip fit between printed parts
screw     = 3.2;   // M3 free fit
boss_d    = 7;     // screw boss outside diameter
boss_hole = 2.9;   // self-tapping M3. Use 4.2 for heat-set inserts.

// ── Cabinet geometry ──────────────────────────────────────────────────────
W            = panel_w + 2*(bezel_lip + wall + 2);   // 208
D            = 130;
deck_front_h = 22;
deck_run     = 85;
deck_rise    = 28;
screen_run   = 19;
screen_rise  = 106;

deck_ang   = atan(deck_rise / deck_run);
screen_ang = atan(screen_run / screen_rise);
deck_len   = sqrt(deck_run*deck_run + deck_rise*deck_rise);
H          = deck_front_h + deck_rise + screen_rise;

PROFILE = [[0,0], [D,0], [D,H], [deck_run+screen_run,H],
           [deck_run, deck_front_h+deck_rise], [0, deck_front_h]];

deck_w    = W - 2*wall - 2*clear;     // plate width, across the cabinet
deck_l    = deck_len - 2*wall;        // plate length, up the slope
open_in   = 9;                        // ledge width around the deck opening
scr_in    = 8;                        // screw inset from the plate edge

// ── Placement helpers. Children are in face-local coords, centred. ────────
// Deck local: +X up the slope, +Y across, +Z out of the surface.
module on_deck() {
  translate([deck_run/2, W/2, deck_front_h + deck_rise/2])
    rotate([0, -deck_ang, 0]) children();
}
// Screen local: +Z up the face, +Y across, +X into the cabinet.
module on_screen() {
  translate([deck_run + screen_run/2, W/2,
             deck_front_h + deck_rise + screen_rise/2])
    rotate([0, screen_ang, 0]) children();
}

deck_screws = [for (x = [-1,1], y = [-1,1])
                 [x*(deck_l/2 - scr_in), y*(deck_w/2 - scr_in)]];

// ── Control layout, in deck-local coords ──────────────────────────────────
enc_d       = 7.6;
btn_big_d   = 12.4;
btn_small_d = 7.0;
dpad_r      = 19;

enc1_y = -deck_w/2 + 26;
dpad_y = -deck_w/2 + 72;
ab_y   =  deck_w/2 - 74;
sys_y  =  deck_w/2 - 47;
enc2_y =  deck_w/2 - 26;

module deck_holes_2d() {
  translate([0, enc1_y]) circle(d = enc_d, $fn = 40);
  translate([0, enc2_y]) circle(d = enc_d, $fn = 40);
  for (a = [0:90:270])
    translate([dpad_r*sin(a), dpad_y + dpad_r*cos(a)]) circle(d = btn_big_d, $fn = 40);
  for (x = [-13, 13]) translate([x, ab_y]) circle(d = btn_big_d, $fn = 40);
  for (x = [-15, 15]) translate([x, sys_y]) circle(d = btn_small_d, $fn = 30);
  for (i = [-2:2], j = [-1:1])                       // buzzer grille
    translate([deck_l/2 - 12 + j*4, i*4]) circle(d = 2, $fn = 16);
  for (p = deck_screws) translate(p) circle(d = screw, $fn = 30);
}

// ── Parts ─────────────────────────────────────────────────────────────────
module shell_solid(w) {
  translate([0, w, 0]) rotate([90,0,0]) linear_extrude(w) polygon(PROFILE);
}

module body() {
  difference() {
    union() {
      difference() {
        shell_solid(W);
        // Hollow with a 2D offset, which keeps the wall constant on every
        // sloping face. Scaling the solid would not.
        translate([0, W - wall, 0]) rotate([90,0,0])
          linear_extrude(W - 2*wall) offset(r = -wall) polygon(PROFILE);
        // Open the rear.
        translate([D - wall, -1, -1]) cube([wall+2, W+2, H+2]);
      }
      // Bosses for the deck plate, standing proud on the inside face.
      on_deck() for (p = deck_screws)
        translate([p[0], p[1], -6]) cylinder(d = boss_d, h = 6.5, $fn = 30);
    }
    // Screen: through-window, deliberately smaller than the panel so a
    // bezel_lip of material remains for the panel to press against.
    on_screen() cube([80, panel_w - 2*bezel_lip, panel_h - 2*bezel_lip], center = true);
    // Recess behind it for the panel PCB to drop into.
    on_screen() translate([pcb_t/2 + wall/2, 0, 0])
      cube([pcb_t + wall, panel_w + 2*clear, panel_h + 2*clear], center = true);
    // Deck opening, smaller than the plate so the plate lands on a ledge.
    on_deck() cube([deck_l - 2*open_in, deck_w - 2*open_in, 80], center = true);
    // Pilot holes in the bosses.
    on_deck() for (p = deck_screws)
      translate([p[0], p[1], -8]) cylinder(d = boss_hole, h = 12, $fn = 24);
  }
}

module deck() {
  difference() {
    translate([-deck_l/2, -deck_w/2, 0])
      linear_extrude(wall) offset(r = 2) offset(r = -2) square([deck_l, deck_w]);
    translate([0,0,-1]) linear_extrude(wall + 2) deck_holes_2d();
  }
}

module back() {
  bw = W - 2*wall - 2*clear;
  bh = H - wall;
  difference() {
    linear_extrude(wall) offset(r = 3) offset(r = -3) square([bw, bh]);
    for (i = [0:6], j = [0:9])                       // vents
      translate([26 + i*24, 26 + j*11, -1])
        linear_extrude(wall+2) offset(r = 1.5) square([12, 1], center = true);
    translate([bw/2, 14, -1])                        // cable exit
      linear_extrude(wall+2) offset(r = 4) square([34, 6], center = true);
    for (x = [9, bw-9], y = [9, bh-9])
      translate([x, y, -1]) cylinder(d = screw, h = wall+2, $fn = 30);
  }
}

part = "all";
if      (part == "body") body();
else if (part == "deck") deck();
else if (part == "back") back();
else { body(); translate([-70,0,0]) deck(); translate([-160,0,0]) back(); }

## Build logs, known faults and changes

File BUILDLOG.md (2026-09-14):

# Build log

Chronological record of what we tried, what broke, and why the design is the
way it is. The README documents the *result*; this documents the *route*.

Each entry is dated and keeps the dead ends in — those are the expensive part.

---

## Hardware as built

### Power rails

The handheld control section uses **common rails**:

- **All grounds are shorted together** — panel supply GND, XIAO GND, UNO Q GND,
  and every button/encoder ground return share one node.
- **Both 3V3 lines are shorted together** — the two HW-040 encoder modules share
  a single 3.3 V rail taken from the UNO Q header.

Two consequences worth remembering:

1. A common ground is *required*, not optional. The HUB75 data lines and the
   button pull-ups are only meaningful relative to a shared reference. Early on,
   driving the panel while its own 5 V rail was absent back-fed it through the
   input ESD clamp diodes — see 2026-09-13 below.
2. The 3.3 V rail is the **only** correct supply for the HW-040 modules. They
   carry onboard pull-ups to VCC, so a 5 V feed would put 5 V onto the UNO Q's
   3.3 V-logic inputs.

### Supply topology

```
5V 2.5A ──────────► Panel VH4
USB charger ──────► XIAO ESP32-S3        (WiFi to UNO Q)
USB-C 5V/3A ──────► UNO Q                (datasheet: PD requests 5V/3A only)
UNO Q 3V3 ────────► both HW-040 modules
        GND ──── common to everything
```

---

## 2026-09-13 — Panel bring-up

**Goal:** get anything at all onto the Waveshare 64×32.

Ruled out driving HUB75 from either half of the UNO Q directly. Linux userspace
has no real-time guarantee, and `rpi-rgb-led-matrix` is Raspberry Pi-specific
(BCM2835 registers). Adafruit_Protomatter has no STM32U5 backend — its STM32
arch is gated on `#if defined(STM32F4_SERIES)`. Offloaded to a XIAO ESP32-S3
driving HUB75 over GDMA.

**Pin budget.** HUB75 needs 13 signals. The XIAO exposes 11 edge GPIO plus four
rear JTAG pads. Put the two least timing-critical lines (address C and D) on the
rear pads, keeping the six colour lines and CLK/LAT/OE on clean edge pins.

### Failures, in order

| Symptom | Cause | Fix |
|---|---|---|
| XIAO never enumerated | Charge-only USB-C cable | Different cable |
| Panel lit with garbage while "unpowered" | Back-fed through input ESD clamp diodes from 13 driven GPIO; rail floated to ~2.5 V and browned out the XIAO | Power the panel first, XIAO second |
| All 32 rows lit but in scrambled order | Address lines B and D crossed | Swapped the pin defines — `xiao_addr` sketch identifies the permutation in one static image |
| Ping and brightness ACKed, frames silently failed | USB CDC RX ring defaults to 256 bytes against a 4096-byte frame | `Serial.setRxBufferSize(8192)` before `begin()` |
| Stream desynchronised permanently | Read both magic bytes in one pass; broke whenever `0xA5` landed at the end of a USB packet | Track the previous byte across loop iterations |
| Serial opened but board unresponsive | pyserial asserts DTR/RTS on open; on the S3's USB Serial/JTAG those drive reset and boot-mode | Clear both *before* opening |

**Result:** 103 fps over USB serial.

---

## 2026-09-13 — Transport moved to WiFi

Wired was chosen first, then reversed. Hosting the XIAO over USB occupies the
UNO Q's only USB-C port, which forces VIN power (7–24 V) and a battery pack to
match. WiFi removes all of it.

Bandwidth was never the constraint: a 64×32 RGB565 frame is 4096 bytes.

**TCP, not UDP** — a frame exceeds the ~1472-byte UDP payload, so UDP would mean
hand-rolling fragmentation and reassembly for no gain at these rates.

### The antenna

The XIAO could see the network but never associated — status 6 (`WL_DISCONNECTED`)
for 30 s, every attempt. Credentials were correct.

| | Networks seen | Target signal |
|---|---|---|
| UNO Q, same desk | 26 | 97 (strong) |
| XIAO, before | 4 | −85 dBm |
| XIAO, after | 16 | **−39 dBm** |

**The XIAO ESP32-S3 has no PCB antenna.** The u.FL antenna was not clipped on.
A 45 dB difference that presents as "wrong WiFi password".

Also: `Tinker Space` is 5 GHz only (ch 36/149). The ESP32-S3 is 2.4 GHz only, so
it could never have joined regardless. Moved everything to a 2.4 GHz SSID.

**Result:** 114 fps over WiFi — faster than USB.

---

## 2026-09-14 — Control deck, Phase 1

**Inputs live on the STM32 side.** Quadrature decoding and debounce need a
jitter-free poll loop; that is what a microcontroller is for and what Linux
userspace is bad at. It also puts both of the UNO Q's brains on the critical
path, which is the board's whole pitch.

### How the two halves talk

Found by inspection rather than documentation:

```
arduino-router --unix-port /var/run/arduino-router.sock \
               --serial-port /dev/ttyHS1 --serial-baudrate 115200
```

STM32 ↔ UART `/dev/ttyHS1` ↔ `arduino-router` ↔ Unix socket ↔ Python.

- **MCU side:** `Arduino_RouterBridge` — `Bridge.provide("name", func)`
- **Python side:** `arduino.app_utils` — `@call()`, `@notify()`, `@provide()`

The Python API ships **inside the App Lab brick container**, not on the host,
which is why `import arduino` fails over SSH.

### Pillow without sudo

`python3-pil` needs root, and the host has no pip, no `ensurepip` and no venv.
Unnecessary: the brick image already carries **PIL 12.3.0, msgpack and arduino**.
Run the code in the container with the router socket mounted:

```bash
docker run --rm --network host \
  -v /var/run/arduino-router.sock:/var/run/arduino-router.sock \
  -v /home/arduino/ledmatrix:/app -w /app \
  --entrypoint python3 ghcr.io/arduino/app-bricks/python-apps-base:0.12.0 script.py
```

### Protocol

One RPC, polled once per frame, packing everything into a single int32 — one
value, no composite msgpack types to get wrong:

```
bits  0-7   buttons held now
bits  8-15  buttons pressed since last poll  (latched, cleared on read)
bits 16-23  encoder 1 delta, signed int8
bits 24-31  encoder 2 delta, signed int8
```

Latching presses on the MCU means a tap between two 30 fps polls is never lost.

### Encoders

Decoded with the 16-entry quadrature table, **not** by counting edges. Cheap
detented encoders bounce, and edge counting turns bounce into phantom counts in
both directions. Illegal transitions map to 0 in the table, so they contribute
nothing. `DETENT_STEPS = 4` because HW-040 emits four transitions per detent.

### Failures

| Symptom | Cause | Fix |
|---|---|---|
| B button read as permanently pressed (`held=0x20`, nothing touched) | D13 drives the onboard LED; its series resistor to ground divides against the ~40 kΩ internal pull-up and holds the pin under threshold | Moved B to **A1**. D13 left unused |

**Result:** bridge RPC round-trips; 7/8 buttons clean before the D13 fix.

---

## 2026-09-14 — B button recovered

Stuck low on three separately verified pins (D13, A1, A5). A5 measured HIGH
bare, then went LOW the moment the button was attached — a controlled
experiment pinning it on the switch, not the pin. After rewiring, A5 reads
HIGH at rest.

Restored as **back/cancel** across the shell and all six games, which frees the
encoder push for pause and gives the console a proper two-button grammar:
A confirms, B goes back, and neither is ever overloaded.

## 2026-09-14 — Encoder 2: faulty module, proven by swap

Isolated in stages rather than guessed at:

1. Turning the right knob changed **no pin anywhere** — not on D5/D6/D7, not on
   A2/A3/A4. The signal path was open.
2. Grounds measured continuous to the Arduino GND pin, killing the
   missing-ground theory. Worth noting the contacts short CLK/DT straight to
   common, so even a missing VCC would still have produced transitions.
3. Shorting the module's own pads to ground produced nothing at the MCU,
   bypassing the encoder component entirely.
4. A **new encoder wired to D5/D6/D7 worked immediately** — 52 transitions on
   CLK, 51 on DT, 10 on the push.

So the original module or its wiring was faulty. Firmware moved back to
D5/D6/D7 and encoder 2 is live.

Also fixed a latent bug found along the way: `Bridge.provide()` binds names on
the router, and the MCU only registered once in `setup()`. Boot before the
router is listening — a coin flip after a power cycle — and the binds fail
silently, leaving the controls invisible to Python forever. Registration now
retries every 2 s until it takes.

With both dials alive, Pong went in (two encoders, two players) and Gear Lab
got a dial per gear.

## 2026-09-14 — Encoder 2 abandoned; console made independent of it

Two encoders were tried on three pin sets. The second module was replaced with
one proven working on D5/D6/D7 (52/51 transitions), then resoldered to the
analog pins, and still read nothing. A CLK/SW swap was found and corrected
(CLK is A4, SW is A2, DT is A3) — still nothing.

Worth recording *why* this was so slow to pin down: a swapped CLK and SW does
not look like a wiring fault from software. The decoder reads a static pin as
CLK against a live DT, which produces an endless +1/-1 alternation that never
accumulates to a whole detent. `enc(1)` reads exactly 0 — indistinguishable
from a disconnected encoder.

**Decision: stop.** Encoder 2 is not on the critical path and the time was
better spent elsewhere. Nothing in the console requires it:

- Pong's player 2 accepts encoder 2 *or* up/down, and falls back to a CPU
  opponent after 3 s of no input, so a kid alone still has a game.
- Gear Lab uses encoder 2 only as an optional second dial; left/right do the
  same job.
- Everything else was already single-encoder.

If it is ever repaired it starts working again with no code change.

## 2026-09-14 — UI pass, done against rendered output

Built `tools/capture.py`, which renders every screen to a contact sheet with
the LED pitch masked in. Judging legibility at 64x32 by reading source code
does not work; looking at the output found problems in minutes that had
survived several sessions.

What it caught:

- **The third menu row was clipped** by the hint bar. Fixed by defining the
  screen as three fixed bands — status 0-5, content 7-23, hints 25-31 — with
  the content band sized to exactly three 6px rows.
- **`DIM` was too dark to read.** At working brightness on a 3 mm pitch panel
  anything under ~120 reads as off. Greys went from 88 to 158.
- **Results lost its "CHARGE" line**, Bit Flip's readout sat on top of the bit
  row, Gear Lab's tooth counts sat on the wheels, Pong's hints overran each
  other, and the scroll arrow was drawn through Snake's high score.
- **Gear Lab's gears read as scattered dots.** Teeth alone do not look like a
  gear at this size; adding a dim rim and a hub fixed it.
- **Breakout's paddle sat below the content band**, in the hint separator.

Also added: scroll arrows on lists that scroll, a two-line help card before
every game, a first-run tutorial that makes you use each control once, and
slide transitions on push/pop. The transition direction is not decoration —
with no window chrome, a hard cut between screens gives no clue whether you
went deeper or came back.

Verified by fuzzing 40,000 frames through the live scene stack.

## 2026-09-14 — Learning side built out

Selection highlighting was a dark fill behind the text. On an LED panel that
is backwards: every pixel lit in the background costs contrast against the
glyphs. Replaced with brightness -- selected row white with a coloured caret,
unselected dimmed, no fill.

Added `skill.py`: per-game adaptive difficulty. Two first-try corrects promote,
two wrongs demote, each game tracked separately. First-try matters, because
arriving at the answer after three guesses is not the same as knowing it.

Added teach-on-error. Every learning game now explains *why* an answer was
wrong in one line and returns you to the same problem.

Three new learning games -- Pattern, Ohm's Way, Angle Hunter -- bringing the
learn track to six, all on a shared adaptive base (`games/learn_base.py`) so
adding more is a small file rather than a copy-paste.

Two layout faults the renderer caught: the teach card clipped its second line,
and the left hint collided with the new "L3 2/6" indicator on the right.

## Open items

- One dial. Encoder 2 abandoned; `enc(1)` returns 0 so one can be refitted later
- Buzzer not yet fitted (passive piezo, A0). `beep()` is already wired
- Encoder direction convention unconfirmed by feel (sign flip is one constant)
- ~~`to_rgb565()` pure-Python loop~~ — done, numpy path at 0.033 ms/frame

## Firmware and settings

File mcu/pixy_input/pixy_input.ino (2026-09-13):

// Pixy control deck -- runs on the UNO Q's STM32U585.
//
// This half exists because quadrature decoding and debounce need a tight,
// jitter-free poll loop, which is what a microcontroller is for and what Linux
// userspace is bad at. It scans at 1 kHz, cleans everything up, and exposes a
// single RPC the Python side calls once per frame.
//
// Deliberately no game logic here. Input only.
//
// Hardware: 2x HW-040 (KY-040) encoders, 4 big tactile, 2 small tactile.
//   HW-040 VCC goes to 3V3, NOT 5V -- the UNO Q's header logic is 3.3 V.
//   The modules carry their own 10k pull-ups on CLK/DT; SW has none, so it
//   uses the internal pull-up like the plain buttons.

#include <Arduino_RouterBridge.h>

// ── Pin map ───────────────────────────────────────────────────────────────
// D0/D1 are the UART, so everything starts at D2.
constexpr int ENC1_CLK = 2,  ENC1_DT = 3,  ENC1_SW = 4;
constexpr int ENC2_CLK = A4, ENC2_DT = A3, ENC2_SW = A2;  // as soldered
constexpr int BTN_UP   = 8,  BTN_DOWN = 9, BTN_LEFT = 10, BTN_RIGHT = 11;
constexpr int BTN_A    = 12, BTN_B   = A5;   // moved off A1; NOT D13, see note
constexpr int BUZZER   = A0;
// D13 is deliberately unused. It drives the onboard LED, whose series resistor
// to ground divides against the ~40k internal pull-up and holds the pin below
// threshold -- a button there reads as permanently pressed.

// Bit positions in the packed reply. Python mirrors this order exactly.
enum : uint8_t {
  BIT_UP = 0, BIT_DOWN, BIT_LEFT, BIT_RIGHT,
  BIT_A, BIT_B, BIT_START, BIT_SELECT
};
constexpr int BTN_PIN[8] = {
  BTN_UP, BTN_DOWN, BTN_LEFT, BTN_RIGHT,
  BTN_A, BTN_B, ENC1_SW, ENC2_SW      // encoder pushes are Start and Select
};

constexpr uint32_t SCAN_INTERVAL_US = 1000;   // 1 kHz
constexpr uint16_t DEBOUNCE_MS      = 8;
constexpr int8_t   DETENT_STEPS     = 4;      // HW-040 emits 4 transitions/detent

// ── Debounced button state ────────────────────────────────────────────────
struct Button {
  uint8_t  stable   = 1;   // 1 = released (pull-up), 0 = pressed
  uint8_t  reading  = 1;
  uint32_t changed  = 0;
};
static Button buttons[8];

static volatile uint8_t btnHeld    = 0;   // currently down
static volatile uint8_t btnPressed = 0;   // went down since last poll -- sticky

// ── Quadrature ────────────────────────────────────────────────────────────
// The 16-entry transition table. Counting edges instead of using this is the
// classic mistake: a cheap detented encoder bounces, and naive counting turns
// that bounce into phantom counts in both directions. Illegal transitions map
// to 0 here, so bounce contributes nothing.
static const int8_t QTAB[16] = {
   0, -1,  1,  0,
   1,  0,  0, -1,
  -1,  0,  0,  1,
   0,  1, -1,  0
};

struct Encoder {
  int pinA, pinB;
  uint8_t  prev = 0;
  int8_t   quarter = 0;             // sub-detent accumulator
  volatile int16_t detents = 0;     // whole detents since last poll
};
static Encoder enc[2] = {
  { ENC1_CLK, ENC1_DT },
  { ENC2_CLK, ENC2_DT }
};

static void scanEncoder(Encoder &e) {
  uint8_t now = (digitalRead(e.pinA) << 1) | digitalRead(e.pinB);
  if (now == e.prev) return;

  e.quarter += QTAB[(e.prev << 2) | now];
  e.prev = now;

  // Only report whole detents, so one physical click is always one step.
  while (e.quarter >= DETENT_STEPS)  { e.quarter -= DETENT_STEPS; e.detents++; }
  while (e.quarter <= -DETENT_STEPS) { e.quarter += DETENT_STEPS; e.detents--; }
}

static void scanButtons(uint32_t nowMs) {
  for (uint8_t i = 0; i < 8; i++) {
    uint8_t raw = digitalRead(BTN_PIN[i]);
    Button &b = buttons[i];

    if (raw != b.reading) {          // bouncing -- restart the settle window
      b.reading = raw;
      b.changed = nowMs;
      continue;
    }
    if (raw == b.stable) continue;
    if (nowMs - b.changed < DEBOUNCE_MS) continue;

    b.stable = raw;
    if (raw == 0) {                  // active low: a press
      btnHeld    |= (1 << i);
      btnPressed |= (1 << i);        // latched so a tap between polls survives
    } else {
      btnHeld    &= ~(1 << i);
    }
  }
}

// ── The one RPC the Linux side calls ──────────────────────────────────────
// Everything is packed into a single int32 rather than a msgpack array: it is
// one value with no composite-type surprises, and it is plenty of room.
//
//   bits  0-7   buttons currently held
//   bits  8-15  buttons pressed since last poll (cleared on read)
//   bits 16-23  encoder 1 delta, signed int8
//   bits 24-31  encoder 2 delta, signed int8
static int32_t pollInput() {
  uint8_t held, pressed;
  int16_t d0, d1;

  // Short critical section: the bridge callback runs on its own Zephyr thread,
  // so without this a poll can land mid-update and lose a press.
  noInterrupts();
  held    = btnHeld;
  pressed = btnPressed;
  btnPressed = 0;
  d0 = enc[0].detents; enc[0].detents = 0;
  d1 = enc[1].detents; enc[1].detents = 0;
  interrupts();

  if (d0 >  127) d0 =  127;  if (d0 < -127) d0 = -127;
  if (d1 >  127) d1 =  127;  if (d1 < -127) d1 = -127;

  return  (uint32_t)held
       | ((uint32_t)pressed      << 8)
       | ((uint32_t)(uint8_t)d0  << 16)
       | ((uint32_t)(uint8_t)d1  << 24);
}

// Raw pin levels, for diagnosing wiring without anyone having to press
// anything at the right moment. Bit order matches RAW_PINS below.
//
// Useful trick for the HW-040 modules: they carry 10k pull-ups to their own
// VCC. If a module's VCC leg is disconnected, those 10k resistors pull toward
// 0 V and beat the MCU's ~40k internal pull-up, so CLK/DT read LOW at rest.
// A powered, idle module reads HIGH. That distinguishes "module unpowered"
// from "module fine, signal wire off".
static const int RAW_PINS[12] = {
  ENC1_CLK, ENC1_DT, ENC1_SW, ENC2_CLK, ENC2_DT, ENC2_SW,
  BTN_UP, BTN_DOWN, BTN_LEFT, BTN_RIGHT, BTN_A, BTN_B
};
static int32_t rawPins() {
  int32_t v = 0;
  for (uint8_t i = 0; i < 12; i++) v |= (digitalRead(RAW_PINS[i]) ? 1L : 0L) << i;
  return v;
}

// Every header pin we are not otherwise using, so a wire can be found wherever
// it actually landed rather than only where it was supposed to go. A0 is
// omitted because it drives the buzzer.
static const int SPARE_PINS[7] = { 5, 6, 7, 13, A1, A1, A1 };
static const int SPARE2_PINS[2] = { A4, A5 };
static int32_t scanAll() {
  int32_t v = 0;
  for (uint8_t i = 0; i < 7; i++) v |= (digitalRead(SPARE_PINS[i]) ? 1L : 0L) << i;
  for (uint8_t i = 0; i < 2; i++) v |= (digitalRead(SPARE2_PINS[i]) ? 1L : 0L) << (7 + i);
  return v;
}

// Short blip. Passive buzzer only -- an active buzzer ignores the frequency.
static void beep(int freq, int ms) {
  tone(BUZZER, freq, ms);
}

void setup() {
  for (uint8_t i = 0; i < 8; i++) pinMode(BTN_PIN[i], INPUT_PULLUP);
  pinMode(ENC1_CLK, INPUT_PULLUP); pinMode(ENC1_DT, INPUT_PULLUP);
  pinMode(ENC2_CLK, INPUT_PULLUP); pinMode(ENC2_DT, INPUT_PULLUP);
  pinMode(BUZZER, OUTPUT);

  for (auto &e : enc) e.prev = (digitalRead(e.pinA) << 1) | digitalRead(e.pinB);

  // Spare header pins as pulled-up inputs, purely so scanAll() can see them.
  for (int p : {5, 6, 7, 13}) pinMode(p, INPUT_PULLUP);
  pinMode(A1, INPUT_PULLUP);

  // Bridge.begin() is deliberately NOT called here. On a cold boot the MCU is
  // running in milliseconds while Linux needs ~40s to start arduino-router, so
  // a begin() in setup() simply fails and the controls stay dead until someone
  // reflashes. loop() brings it up instead, once the router is actually there.
  Monitor.begin(115200);
  Monitor.println("pixy control deck starting");
}

// Bringing the bridge up has to be retried, in two stages.
//
// Bridge.begin() only short-circuits once it has succeeded; a failed call
// re-allocates the transport, client, server and a fresh Zephyr thread every
// time. So retries are bounded -- enough to cover Linux booting, not enough to
// leak indefinitely if the router never appears.
//
// provide() then binds each name on the router. Both stages fail silently, and
// a silent failure here means the controls never work at all.
static bool bridgeUp = false;
static bool registered = false;

static void tryBridge() {
  static uint32_t nextTry = 0;
  static uint8_t attempts = 0;
  if (registered || millis() < nextTry) return;
  nextTry = millis() + 3000;

  if (!bridgeUp) {
    if (attempts++ > 30) return;        // ~90s, then give up rather than leak
    bridgeUp = Bridge.begin();
    if (!bridgeUp) return;
    Monitor.println("bridge up");
  }

  registered = Bridge.provide("poll_input", pollInput)
            && Bridge.provide("beep", beep)
            && Bridge.provide("raw_pins", rawPins)
            && Bridge.provide("scan_all", scanAll);
  if (registered) Monitor.println("pixy control deck registered");
}

void loop() {
  tryBridge();

  static uint32_t nextScan = 0;
  uint32_t nowUs = micros();
  if ((int32_t)(nowUs - nextScan) < 0) return;
  nextScan = nowUs + SCAN_INTERVAL_US;

  uint32_t nowMs = millis();
  scanEncoder(enc[0]);
  scanEncoder(enc[1]);
  scanButtons(nowMs);
}

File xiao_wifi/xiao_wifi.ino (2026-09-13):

// Panel receiver over WiFi, for the UNO Q project.
//
// Same dumb-display role as the USB version: it owns the HUB75 refresh and
// nothing else. The UNO Q renders every frame in Python and streams finished
// RGB565 over TCP.
//
// TCP rather than UDP on purpose -- a frame is 4096 bytes, well past the ~1472
// byte UDP payload limit, so UDP would mean writing fragmentation and
// reassembly by hand. TCP already does it, and 4KB a frame is nowhere near
// saturating the link.
//
// Wire protocol is unchanged from the serial build:
//   0xA5 0x5A <cmd> <len:uint16 LE> <payload...>
//     0x01 frame (4096 bytes RGB565, big endian per pixel)
//     0x02 brightness (1 byte)
//     0x03 clear
//     0x04 ping
//   Each handled command is acknowledged with a single 0x06 byte.

#include <WiFi.h>
#include <ESP32-HUB75-MatrixPanel-I2S-DMA.h>
#include "secrets.h"

#define PANEL_W     64
#define PANEL_H     32
#define PANEL_CHAIN 1
#define TCP_PORT    3333

#define P_R1   1   // D0
#define P_G1   2   // D1
#define P_B1   3   // D2
#define P_R2   4   // D3
#define P_G2   5   // D4
#define P_B2   6   // D5
#define P_A   43   // D6
#define P_B   41   // MTDI rear pad -- wired to panel B
#define P_C   40   // rear pad, MTDO
#define P_D   44   // D7 -- wired to panel D
#define P_E   -1   // unused: 64x32 is 1/16 scan
#define P_CLK  7   // D8
#define P_LAT  8   // D9
#define P_OE   9   // D10

#define CMD_FRAME      0x01
#define CMD_BRIGHTNESS 0x02
#define CMD_CLEAR      0x03
#define CMD_PING       0x04
#define ACK            0x06

static const uint16_t FRAME_BYTES = PANEL_W * PANEL_H * 2;

MatrixPanel_I2S_DMA *display = nullptr;
WiFiServer server(TCP_PORT);
WiFiClient client;
static uint8_t frame[FRAME_BYTES];

static void banner(const char *l1, const char *l2, uint16_t colour) {
  display->clearScreen();
  display->setTextSize(1);
  display->setTextColor(colour);
  display->setCursor(1, 6);
  display->print(l1);
  if (l2) { display->setCursor(1, 18); display->print(l2); }
  display->flipDMABuffer();
}

// Split "192.168.1.42" across two lines so it fits 64px at the 6px base font.
static void showAddress(IPAddress ip) {
  char top[20], bottom[20];
  snprintf(top, sizeof(top), "%u.%u.", ip[0], ip[1]);
  snprintf(bottom, sizeof(bottom), "%u.%u", ip[2], ip[3]);
  banner(top, bottom, display->color565(0, 220, 255));
}

static bool readExact(uint8_t *dst, size_t want, uint32_t timeoutMs = 3000) {
  size_t got = 0;
  uint32_t deadline = millis() + timeoutMs;
  while (got < want) {
    if (millis() > deadline || !client.connected()) return false;
    int n = client.read(dst + got, want - got);
    if (n > 0) got += n;
  }
  return true;
}

static void blitFrame() {
  size_t i = 0;
  for (int y = 0; y < PANEL_H; y++) {
    for (int x = 0; x < PANEL_W; x++) {
      display->drawPixel(x, y, ((uint16_t)frame[i] << 8) | frame[i + 1]);
      i += 2;
    }
  }
  display->flipDMABuffer();
}

void setup() {
  HUB75_I2S_CFG::i2s_pins pins = {
    P_R1, P_G1, P_B1, P_R2, P_G2, P_B2,
    P_A, P_B, P_C, P_D, P_E,
    P_LAT, P_OE, P_CLK
  };
  HUB75_I2S_CFG mxconfig(PANEL_W, PANEL_H, PANEL_CHAIN, pins);
  mxconfig.clkphase    = false;
  mxconfig.double_buff = true;

  display = new MatrixPanel_I2S_DMA(mxconfig);
  if (!display->begin()) return;
  display->setBrightness8(60);
  display->clearScreen();

  Serial.begin(115200);
  delay(500);
  Serial.println();
  Serial.printf("target SSID: \"%s\" (%u chars)\n", WIFI_SSID, strlen(WIFI_SSID));
  Serial.printf("pass length: %u chars\n", strlen(WIFI_PASS));

  banner("WIFI", "SCAN", display->color565(255, 180, 0));

  WiFi.mode(WIFI_STA);
  WiFi.setSleep(false);          // sleep adds latency and stutters streaming
  WiFi.disconnect(true);
  delay(200);

  // Scan first: proves whether the radio can even see the target network,
  // which separates "wrong password" from "wrong band / out of range".
  int n = WiFi.scanNetworks();
  Serial.printf("scan found %d networks:\n", n);
  bool seen = false;
  for (int i = 0; i < n; i++) {
    bool match = (WiFi.SSID(i) == WIFI_SSID);
    if (match) seen = true;
    Serial.printf("  %2d %-32s ch%-3d %4d dBm %s\n", i,
                  WiFi.SSID(i).c_str(), WiFi.channel(i), WiFi.RSSI(i),
                  match ? "  <-- TARGET" : "");
  }
  Serial.printf("target visible: %s\n", seen ? "YES" : "NO");

  banner("WIFI", "...", display->color565(255, 180, 0));
  WiFi.begin(WIFI_SSID, WIFI_PASS);

  uint32_t deadline = millis() + 30000;
  while (WiFi.status() != WL_CONNECTED && millis() < deadline) {
    delay(1000);
    Serial.printf("  status=%d\n", WiFi.status());
  }

  if (WiFi.status() != WL_CONNECTED) {
    // 1=SSID not found  4=auth failed (usually a wrong password)  6=disconnected
    Serial.printf("FAILED, final status=%d\n", WiFi.status());
    banner("WIFI", "FAIL", display->color565(255, 0, 0));
    return;
  }
  Serial.printf("connected, IP=%s RSSI=%d\n",
                WiFi.localIP().toString().c_str(), WiFi.RSSI());

  server.begin();
  server.setNoDelay(true);       // without this, Nagle batches frames and stutters
  showAddress(WiFi.localIP());   // panel shows where to connect
}

void loop() {
  if (!client || !client.connected()) {
    client = server.available();
    if (!client) { delay(5); return; }
    client.setNoDelay(true);
  }

  static uint8_t prev = 0;
  if (client.available() <= 0) return;
  uint8_t b = (uint8_t)client.read();
  if (prev != 0xA5 || b != 0x5A) { prev = b; return; }
  prev = 0;

  uint8_t header[3];
  if (!readExact(header, 3)) return;
  uint8_t  cmd = header[0];
  uint16_t len = (uint16_t)header[1] | ((uint16_t)header[2] << 8);

  switch (cmd) {
    case CMD_FRAME:
      if (len != FRAME_BYTES) return;
      if (readExact(frame, FRAME_BYTES)) { blitFrame(); client.write(ACK); }
      break;
    case CMD_BRIGHTNESS: {
      uint8_t v;
      if (len == 1 && readExact(&v, 1)) { display->setBrightness8(v); client.write(ACK); }
      break;
    }
    case CMD_CLEAR:
      display->clearScreen();
      display->flipDMABuffer();
      client.write(ACK);
      break;
    case CMD_PING:
      client.write(ACK);
      break;
  }
}

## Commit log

2026-09-13 Initial commit: UNO Q driving a 64x32 HUB75 panel via XIAO ESP32-S3
    Rendering runs in Python on the UNO Q's Linux side (Pillow: text, images,
    GIFs, scrolling). The ESP32-S3 holds no application logic -- it receives
    finished RGB565 frames over TCP and blits them to the panel via GDMA.
    A HUB75 panel has no framebuffer, so something must bit-bang 13 signals at
    100+ refreshes/sec. Linux userspace has no real-time guarantee, and
    Protomatter has no STM32U5 backend, so the pixel pump is offloaded to the
    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
2026-09-13 Phase 1: control deck input over the UNO Q's MCU bridge
    Adds the input spine for Pixy: 2x HW-040 encoders, 4 directional buttons,
    A/B, and the encoder pushes as Start/Select.
    Inputs live on the STM32 side because quadrature decoding and debounce need
    a jitter-free poll loop. It scans at 1 kHz and exposes one RPC that packs
    held buttons, latched presses and both encoder deltas into a single int32,
    which Python calls once per frame. Latching presses on the MCU means a tap
    between frames is never lost.
    Encoders use the 16-entry quadrature table rather than edge counting --
    cheap detented encoders bounce, and edge counting turns that into phantom
    counts in both directions. Illegal transitions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
    [pixy_input.ino]
2026-09-13 Move B button off D13 to A1
    D13 drives the onboard LED. Its series resistor to ground divides against the
    ~40k internal pull-up and holds the pin below threshold, so a button there
    reads as permanently pressed. Confirmed on hardware: held=0x20 with nothing
    pressed, all seven other buttons clean.
2026-09-13 Add BUILDLOG.md and document the control deck wiring
    BUILDLOG tracks iterations and dead ends in detail, separate from the README's
    description of the finished state. Records the common ground and 3V3 rails on
    the handheld section, the router-bridge discovery, and the container route to
    Pillow without sudo.
2026-09-13 Pixy console: shell, six games, Charge economy
    Drops encoder 2 and the B button -- both confirmed hardware faults -- and
    redesigns around the six working controls: encoder 1, A, START (encoder push)
    and the four directions.
    Core: a 3x5 bitmap font (PIL's default eats a third of a 32-row screen and
    anti-aliases into mush), a Canvas that knows the 6/20/6 status/content/hint
    split, a scene stack, and a JSON profile.
    Games: Gate Keeper, Bit Flip and Gear Lab earn Charge; Breakout, Snake and
    Simon spend it. Arcade unlocks are permanent one-time purchases rather than
    pay-per-play, so a kid short on Charge is never locked out of the console.
    Fixes an ACK backpressure deadlock: the receiver ackno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
    [panel.py]
2026-09-13 Add board/pixy.sh launcher
    Runs the console as a detached container so it survives logout, instead of
    dying with whatever SSH session started it. A docker run left attached to a
    killed session keeps running and keeps pushing frames, which showed up as the
    panel thrashing between two programs.
2026-09-13 Restore B as back now that the button is fixed
    B was stuck on D13, A1 and A5. A5 read HIGH bare and LOW once the button was
    attached, which pinned it on the switch rather than the pin; rewiring fixed it.
    Gives the console a proper two-button grammar -- A confirms, B goes back --
    instead of overloading the encoder push for both, and frees START for pause.
    Games now use named button constants rather than raw indices.
    Re-fuzzed 20,000 frames through the scene stack.
2026-09-13 Encoder 2 alive: Pong, two-dial Gear Lab, RPC retry
    The original encoder 2 module was faulty. Proven by swap: a new encoder on
    D5/D6/D7 gave 52/51 transitions immediately, where shorting the old module's
    own pads to ground produced nothing at the MCU. Firmware moved back to
    D5/D6/D7.
    Adds Pong -- two encoders, two players, the game that justifies putting dials
    on this console at all. Gear Lab now has a dial per gear so both sides of the
    ratio are the player's to set.
    Also fixes a latent bug: Bridge.provide() binds on the router, and the MCU
    registered only once in setup(). Booting before the router listens made the
    binds fail silently and the controls invisible to Python until reflashed.
    R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
    [pixy_input.ino]
2026-09-13 Make the console fully independent of encoder 2
    Encoder 2 defeated three pin sets and a module swap. Stopping there: it is not
    on the critical path.
    Pong's player 2 now takes encoder 2 or up/down, and hands the paddle to a CPU
    opponent after 3s of no input, so a lone player still has a game and a second
    player can join mid-rally just by touching a control. If encoder 2 is ever
    repaired it resumes working with no code change.
    Fuzzed 25,000 frames with encoder 2 pinned at zero, matching the hardware.
    [pixy_input.ino]
2026-09-13 Add 3D-printable enclosure
    Wedge cabinet in OpenSCAD: panel leans back 10 deg, control deck slopes 18 deg.
    Three parts, no supports, ~150 g of filament at normal settings.
    The screen aperture is deliberately 4 mm smaller than the panel all round, so
    the panel seats against that lip from behind rather than needing fasteners
    through its face. The deck plate lands on a ledge and screws into four bosses,
    keeping load off the panel face.
    Hollowing uses a 2D offset on the side profile rather than scaling the solid,
    which is what keeps the wall constant on both sloping faces.
    All three parts render manifold with zero errors and were checked visually.
    panel_w/panel_h are confirmed from Waveshare;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
    [back.stl, bezel.stl, body.stl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]
2026-09-13 UI pass: legibility, discoverability, tutorial, transitions
    Judged against rendered output rather than source. tools/capture.py renders
    every screen to a contact sheet with the LED pitch masked in, which found
    layout faults in minutes that had survived several sessions.
    Layout is now three fixed bands -- status 0-5, content 7-23, hints 25-31 --
    with the content band sized to exactly three 6px rows. The third menu row was
    being clipped by the hint bar.
    DIM went from 88 to 158. Below about 120 a grey reads as off on a 3mm pitch
    panel at working brightness, which is why so much text was invisible.
    Fixed collisions in Results, Bit Flip, Gear Lab, Pong and Breakout, and kept
    the scroll arrow o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
2026-09-14 Adaptive learning: 6 games, teach-on-error, brightness selection
    Selection was a dark fill behind text. On an LED panel that is backwards --
    lighting background pixels costs contrast against the glyphs. Now selected
    rows are white with a coloured caret and unselected rows are dimmed, with no
    fill at all.
    Adds skill.py: per-game adaptive difficulty. Two first-try corrects promote,
    two wrongs demote, tracked per game so binary can be hard while ratios stay
    gentle. First-try is what counts toward promotion -- arriving after three
    guesses is not knowing it. Charge scales with level.
    Adds teach-on-error across every learning game: a wrong answer explains why in
    one line, then returns you to the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
2026-09-14 Charge shown as a coin and a number, not a battery
    A battery gauge on a battery-powered handheld reads as power remaining, which
    is not what it means. A coin is unambiguously currency, and the exact figure
    is what matters anyway -- the question is always whether you can afford the
    next unlock, which a bar can only approximate.
    Menu labels are now clipped against the width the note actually needs rather
    than a fixed character count, so a title and its level badge stop colliding.
    GATE KEEPER renamed GATES to fit rather than be truncated.
    Fuzzed 50,000 frames with a four-digit balance to check the widest case.
2026-09-14 Harder, less predictable learning games across eight levels
    Angle loses its target ray. Showing both the guideline and a live readout of
    your own angle made it a matching exercise; now you are given the number and
    have to find it, with the readout itself hidden past level 1 and tolerance
    tightening from 16 degrees to 3.
    Gates: the target was always the opposite of the current output, which is
    guessable without reading the gate. It is now genuinely random, with the
    inputs re-rolled until the puzzle needs work. From level 5 the gate name is
    hidden entirely -- flip inputs, watch the output, work out what it must be.
    Bit Flip hides the running total from level 6. Pattern gains squares and
    grow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
2026-09-14 Add Hackster.io writeup and submission checklist
    HACKSTER.md is the project story, ready to paste into the Story editor.
    docs/SUBMISSION.md carries the sidebar fields -- components, tools, tags --
    and the list of images to upload.
    Generated presentation images from the live code rather than mock-ups, so what
    readers see is what the panel renders.
    [bezel.stl]
2026-09-14 Add build guide, real photos, diagrams and the printed enclosures
    HACKSTER.md rewritten as a structured build document: intention, what it is,
    architecture, a quick start for the experienced, then a step-by-step guide.
    Adds the enclosures actually built and printed -- display housing (199x104x45)
    and handheld controller (128x88x35) -- measured from the STLs rather than
    assumed. The OpenSCAD desktop cabinet stays, clearly labelled as designed but
    not printed.
    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
    [display_housing.stl, handheld_controller.stl]
